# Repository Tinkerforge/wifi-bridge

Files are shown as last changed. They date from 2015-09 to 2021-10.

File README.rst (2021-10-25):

WIFI Bridge
===========

**This product is currently Work In Progress.**

This repository contains the hardware design files.

Repository Content
------------------

hardware/:
 * Contains kicad project files and additionally schematics as pdf

datasheets/:
 * Contains datasheets for sensors and complex ICs that are used

Hardware
--------

The hardware is designed with the open source EDA Suite KiCad
(http://www.kicad.org). Before you are able to open the files,
you have to install the Tinkerforge kicad-libraries
(https://github.com/Tinkerforge/kicad-libraries). You can either clone
them directly in hardware/ or clone them in a separate folder and
symlink them into hardware/
(ln -s kicad_path/kicad-libraries project_path/hardware). After that you
can open the .pro file in hardware/ with kicad and from there view and
modify the schematics and the PCB layout.

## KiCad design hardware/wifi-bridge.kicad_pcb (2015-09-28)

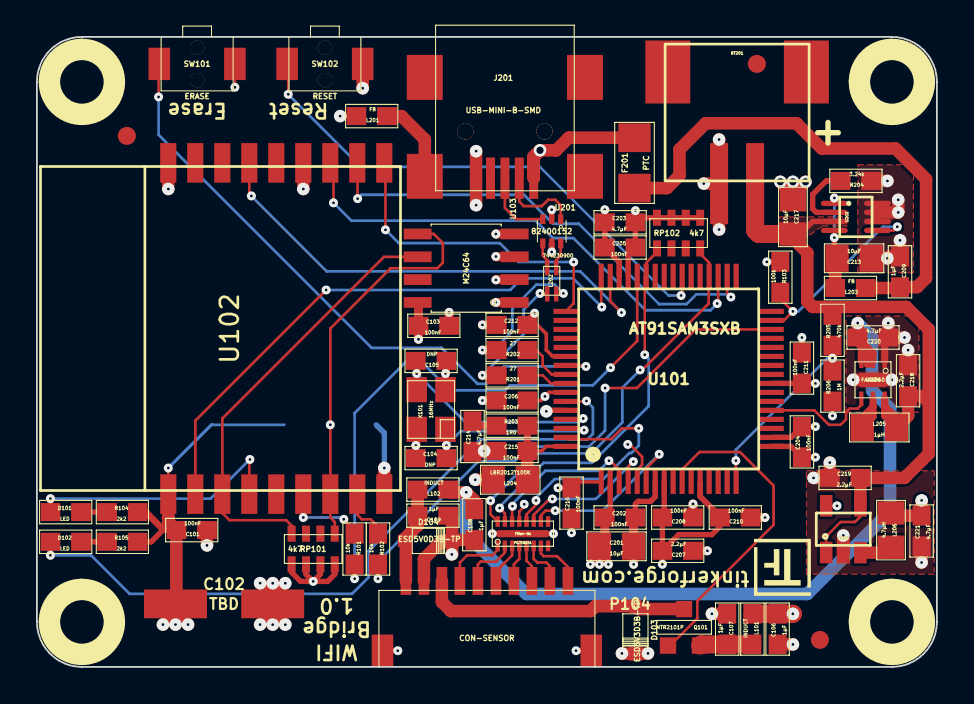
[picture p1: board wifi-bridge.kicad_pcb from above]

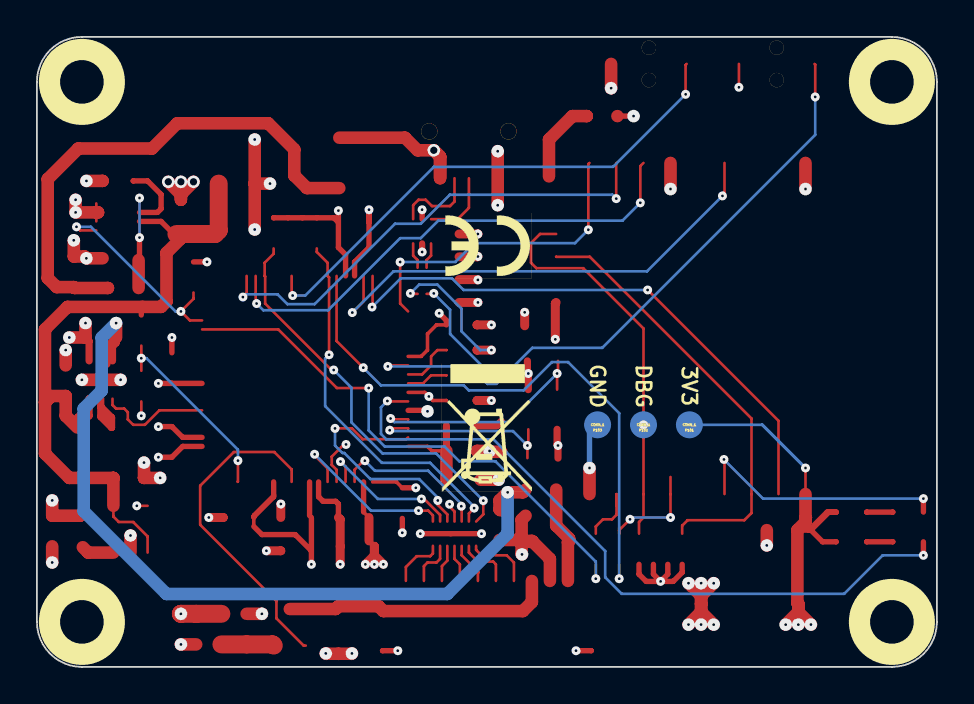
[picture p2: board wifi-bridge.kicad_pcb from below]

Board: 4 copper layers, 50.0 x 35.0 mm, 83 parts (5 on the bottom side), 62 nets.

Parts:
BT201: BATTERY; JST-PH-SM4-2
C101, C103, C202, C204, C205, C206, C208, C210, C211, C212, C215, C216: 100nF; 0603E
C102: TBD; ELKO_63
C104, C105: DNP; 0603E
C106, C107, C108, C109, C209: 1µF; 0603E
C201, C213, C217: 10µF; 0805E
C203, C214, C220, C221: 4.7µF; 0603E
C207, C218, C219: 2.2µF; 0603E
D101, D102: LED; 0603E
D103: ESD3V3D3B-TP; SOD-323
D104: ESD5V0D3B-TP; SOD-323
F201: PTC; 1206E
FILTER101: Filter-8x; DFN16-33x135
Fiducial_Mark: VAL**; Fiducial_Mark
Fiducial_Mark#2, Fiducial_Mark#3: VAL**; Fiducial_Mark
J201: USB-MINI-B-SMD
L101, L102: INDUCT; 0603E
L201, L203: FB; 0603E
L202: 744230900; WE-CNSW-0603
L204: LBR2012T100K; 0805E
L205: 1µH; 0805E
L206: 4.7µH; 0805E
P101, P102, P103: CONN_1; TSTPT
P104: CON-SENSOR
Q101: NTR2101P; SOT23GDS
R101, R102: 10k; 0603E
R103: 100k; 0603E
R104, R105: 2k2; 0603E
R201, R202: 27; 0603E
R203: 1R0; 0603E
R204: 3.24k; 0603E
R205: 470k; 0603E
R206: 1M; 0603E
RP101, RP102: 4k7; 0603X4
SW101: ERASE; TACT-SWITCH
SW102: RESET; TACT-SWITCH
U101: AT91SAM3SXB; LQFP64
U102: ESP8266_WROOM02
U103: M24C64; SOIC8
U104, U105, U106, U107: DRILL; DRILL_NP
U201: 82400152; SOT563-SPEC
U202: AAT3681A; SC70JW-8
U203: PAM2301; TSOT-25
U204: FAN4860; UMLP_22
VAL: WEEE_7mm_back
VAL#2: CE_5mm
X101: 16MHz; CRYSTAL_3225

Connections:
3V3: C101.1, C102.1, C103.2, C106.1, C201.1, C202.1, C203.1, C204.1, C205.1, C206.1, C216.1, C221.1, L101.2, L206.2, P101.1, R103.2, R104.1, R105.1, RP101.1, RP101.2, RP101.3, RP101.4, RP102.1, RP102.2, RP102.3, RP102.4, SW101.2, U101.1, U101.7, U101.18, U101.45, U101.58, U102.1, U103.1, U103.8, U203.5
5VEN: U101.21, U204.4
+5V: C108.1, C220.1, L102.2, U204.2, U204.3
B-ADR: FILTER101.14, U101.3
B-IO1: FILTER101.13, U101.5
B-IO2: FILTER101.12, U101.63
B-IO3: FILTER101.11, U101.4
B-IO4: FILTER101.10, U101.6
B-SCL: FILTER101.16, RP102.8, U101.36
B-SDA: FILTER101.15, RP102.5, U101.43
CHST: R103.1, U101.31, U202.5
D+: R201.2, U101.57
D-: R202.2, U101.56
GND: BT201.2, C101.2, C102.2, C103.1, C104.2, C105.2, C106.2, C107.2, C108.2, C109.2, C201.2, C202.2, C203.2, C204.2, C205.2, C206.2, C207.2, C208.2, C209.2, C210.2, C211.2, C212.2, C213.2, C214.2, C215.2, C216.2, C217.2, C218.2, C219.2, C220.2, C221.2, D103.2, D104.2, FILTER101.EXP, J201.5, L201.1, P103.1, P104.2, P104.EP, R204.2, R206.2, SW102.2, U101.2, U101.17, U101.46, U101.60, U102.9, U102.13, U102.18, U103.2, U103.3, U103.4, U201.2, U202.6, U202.7, U202.8, U203.2, U204.1, U204.EP, X101.3
LED: D102.2, U101.59
unnamed: C104.1, U101.62, X101.1
unnamed: C105.1, U101.61, X101.2
unnamed: C107.1, L101.1, Q101.S
unnamed: C109.1, D104.1, L102.1, P104.1
unnamed: C207.1, C208.1, C210.1, C211.1, C212.1, L204.1, U101.8, U101.12, U101.24, U101.54
unnamed: C209.1, F201.2, L203.2
unnamed: C213.1, L203.1, U202.1, U202.4
unnamed: C214.1, R203.2
unnamed: C215.1, L204.2, R203.1, U101.64
unnamed: D101.1, R104.2
unnamed: D101.2, U102.4
unnamed: D102.1, R105.2
unnamed: D103.1, P104.3, Q101.D
unnamed: F201.1, J201.1, U201.5
unnamed: FILTER101.1, P104.4
unnamed: FILTER101.2, P104.5
unnamed: FILTER101.3, P104.6
unnamed: FILTER101.4, P104.7
unnamed: FILTER101.5, P104.8
unnamed: FILTER101.6, P104.9
unnamed: FILTER101.7, P104.10
unnamed: J201.2, U201.1
unnamed: J201.3, U201.3
unnamed: J201.6, L201.2
unnamed: L202.1, R201.1
unnamed: L202.2, U201.4
unnamed: L202.3, U201.6
unnamed: L202.4, R202.1
unnamed: L205.2, U204.5
unnamed: L206.1, U203.3
unnamed: R101.2, U102.6
unnamed: R102.2, U102.8
unnamed: R204.1, U202.2
unnamed: SW101.1, U101.55
unnamed: SW102.1, U101.39
SW-3V3: Q101.G, U101.10
VBAT: R205.2, R206.1, U101.16
VCC: BT201.1, C217.1, C218.1, C219.1, L205.1, R205.1, U202.3, U203.1, U203.4, U204.6
W-EN: U101.48, U102.2
W-GP: U101.49, U102.10
W-IO0: R102.1, U101.30
W-IO15: R101.1, U101.44
W-RST: U101.47, U102.15
W-RXD: U101.34, U102.11
W-SCL: RP101.8, U102.3, U103.6
W-SDA: P102.1, RP101.5, U102.7, U103.5
W-TXD: U101.35, U102.12

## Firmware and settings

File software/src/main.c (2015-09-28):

/* stepper-brick
 * Copyright (C) 2010-2013 Olaf Lüke <olaf@tinkerforge.com>
 *
 * main.c: Stepper Brick startup code
 *
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
 * You should have received a copy of the GNU Lesser General Public
 * License along with this library; if not, write to the
 * Free Software Foundation, Inc., 59 Temple Place - Suite 330,
 * Boston, MA 02111-1307, USA.
 */

#include <stdbool.h>
#include <stdint.h>
#include <stdio.h>
#include <stdlib.h>

#include "bricklib/free_rtos/include/FreeRTOS.h"
#include "bricklib/free_rtos/include/task.h"

#include "bricklib/com/i2c/i2c_pca9549/i2c_pca9549.h"
#include "bricklib/com/spi/spi_stack/spi_stack_master.h"
#include "bricklib/com/spi/spi_stack/spi_stack_slave.h"
#include "bricklib/com/spi/spi_stack/spi_stack_common.h"
#include "bricklib/com/i2c/i2c_eeprom/i2c_eeprom_master.h"
#include "bricklib/com/i2c/i2c_eeprom/i2c_eeprom_slave.h"
#include "bricklib/com/usb/usb.h"
#include "bricklib/logging/logging.h"
#include "bricklib/bricklet/bricklet_init.h"
#include "bricklib/drivers/uid/uid.h"
#include "bricklib/drivers/wdt/wdt.h"
#include "bricklib/drivers/pio/pio.h"
#include "bricklib/utility/init.h"
#include "bricklib/utility/profiling.h"
#include "bricklib/utility/led.h"
#include "bricklib/logging/logging.h"

#include "config.h"
#include "bricklib/utility/util_definitions.h"

void vApplicationStackOverflowHook(xTaskHandle *pxTask, signed char *pcTaskName) {
	while(true);
}

int main() {

	brick_init();
	led_init();
	Pin ch_st = PIN_CH_ST;
	PIO_Configure(&ch_st, 1);
	while(1) {	
		if(PIO_Get(&ch_st)) {
			led_toggle(LED_STD_BLUE);
		}
		else {
			led_on(LED_STD_BLUE);
		}
		SLEEP_MS(100);
		wdt_restart();
	}
}

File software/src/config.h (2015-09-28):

/* wifi-bridge
 * Copyright (C) 2015 Bastian Nordmeyer <bastian@tinkerforge.com>
 *
 * config.h: Wifi-Bridge specific configuration
 *
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
 * You should have received a copy of the GNU Lesser General Public
 * License along with this library; if not, write to the
 * Free Software Foundation, Inc., 59 Temple Place - Suite 330,
 * Boston, MA 02111-1307, USA.
 */

#ifndef CONFIG_H
#define CONFIG_H

#include "bricklib/drivers/board/sam3s/SAM3S.h"
#include <stdbool.h>

#define BRICK_FIRMWARE_VERSION_MAJOR 1
#define BRICK_FIRMWARE_VERSION_MINOR 0
#define BRICK_FIRMWARE_VERSION_REVISION 0

#define BRICK_HARDWARE_VERSION_MAJOR 1
#define BRICK_HARDWARE_VERSION_MINOR 0
#define BRICK_HARDWARE_VERSION_REVISION 0

#define BRICK_DEVICE_IDENTIFIER 15

// ************** DEBUG SETTINGS **************
#define DEBUG_SPI_STACK 1
#define DEBUG_I2C_EEPROM 0
#define DEBUG_STARTUP 1
#define DEBUG_BRICKLET 1
#define DEBUG_STEPPER 1
//#define PROFILING
//#define PROFILING_TIME 100 // After how many seconds profiling is printed

#define DISABLE_JTAG_ON_STARTUP
//#define LOGGING_SERIAL
//#define LOGGING_LEVEL LOGGING_DEBUG
#define LOGGING_LEVEL LOGGING_NONE


// ************** BRICK SETTINGS **************

// Frequencies
#define BOARD_MCK      64000000 // Frequency of brick
#define BOARD_MAINOSC  16000000 // Frequency of oscillator
#define BOARD_ADC_FREQ 16000000 // Frequency of ADC
#define BOARD_OSC_EXTERNAL      // Use external oscillator


// UART for console output (printf)
#define PIN_CONSOLE_RXD  {1 << 21, PIOA, ID_PIOA, PIO_PERIPH_A, PIO_DEFAULT}
#define PIN_CONSOLE_TXD  {1 << 22, PIOA, ID_PIOA, PIO_PERIPH_A, PIO_DEFAULT}

#define CONSOLE_BAUDRATE 115200
#define CONSOLE_USART    USART1
#define CONSOLE_ID       ID_USART1
#define CONSOLE_PINS     {PIN_CONSOLE_RXD, PIN_CONSOLE_TXD}

#define PINS_UART        {PIN_CONSOLE_RXD, PIN_CONSOLE_TXD}

// TWI
// TWI version
#define TWI_V3XX

// TWI stack definitions (for reading of eeproms from Bricks in stack)
#define TWI_STACK           TWI1
#define PIN_TWI_TWD_STACK   {1 << 4, PIOB, ID_PIOB, PIO_PERIPH_A, PIO_DEFAULT}
#define PIN_TWI_TWCK_STACK  {1 << 5, PIOB, ID_PIOB, PIO_PERIPH_A, PIO_DEFAULT}
#define PINS_TWI_STACK      PIN_TWI_TWD_STACK, PIN_TWI_TWCK_STACK

// TWI bricklet definitions (for bricklets, spi select and brick specific
//                           functions)
#define TWI_BRICKLET           TWI0
#define PIN_TWI_TWD_BRICKLET   {1 << 3, PIOA, ID_PIOA, PIO_PERIPH_A, PIO_DEFAULT}
#define PIN_TWI_TWCK_BRICKLET  {1 << 4, PIOA, ID_PIOA, PIO_PERIPH_A, PIO_DEFAULT}
#define PINS_TWI_BRICKLET      PIN_TWI_TWD_BRICKLET, PIN_TWI_TWCK_BRICKLET

// USB
// USB VBUS monitoring pin for USB plug and play
#define PIN_USB_DETECT  {1 << 26, PIOA, ID_PIOA, PIO_INPUT, PIO_DEFAULT}
// USB product descriptor (name of brick)
#define PRODUCT_DESCRIPTOR { \
	USBStringDescriptor_LENGTH(13), \
    USBGenericDescriptor_STRING, \
    USBStringDescriptor_UNICODE('S'), \
    USBStringDescriptor_UNICODE('t'), \
    USBStringDescriptor_UNICODE('e'), \
    USBStringDescriptor_UNICODE('p'), \
    USBStringDescriptor_UNICODE('p'), \
    USBStringDescriptor_UNICODE('e'), \
    USBStringDescriptor_UNICODE('r'), \
    USBStringDescriptor_UNICODE(' '), \
    USBStringDescriptor_UNICODE('B'), \
    USBStringDescriptor_UNICODE('r'), \
    USBStringDescriptor_UNICODE('i'), \
    USBStringDescriptor_UNICODE('c'), \
    USBStringDescriptor_UNICODE('k') \
}


// SPI
#define PIN_SPI_MISO        {1 << 12, PIOA, ID_PIOA, PIO_PERIPH_A, PIO_DEFAULT}
#define PIN_SPI_MOSI        {1 << 13, PIOA, ID_PIOA, PIO_PERIPH_A, PIO_DEFAULT}
#define PIN_SPI_SPCK        {1 << 14, PIOA, ID_PIOA, PIO_PERIPH_A, PIO_DEFAULT}

#define PINS_SPI            PIN_SPI_MISO, PIN_SPI_MOSI, PIN_SPI_SPCK

#define PIN_SPI_SELECT_SLAVE  {1 << 11, PIOA, ID_PIOA, PIO_PERIPH_A, PIO_DEFAULT}

// LED
#define PIN_LED_STD_BLUE    {1 <<13, PIOB, ID_PIOB, PIO_OUTPUT_1, PIO_DEFAULT}
//#define PIN_LED_STD_RED     {1 << 10, PIOA, ID_PIOA, PIO_OUTPUT_1, PIO_DEFAULT}
#define PINS_STD_LED        PIN_LED_STD_BLUE
#define PINS_LED            PINS_STD_LED

#define LED_STD_BLUE        0
#define LED_STD_RED         1


// Brick Detect
// Set low by master
// TODO: Change name
#define PIN_DETECT        {1 << 6, PIOB, ID_PIOB, PIO_OUTPUT_0, PIO_DEFAULT}

// Pin charge status
#define PIN_CH_ST        {1 << 8, PIOA, ID_PIOA, PIO_INPUT, PIO_PULLUP}



// ************** INTERRUPT PRIORITIES ***********
#define PRIORITY_EEPROM_MASTER_TWI0  1
#define PRIORITY_EEPROM_SLAVE_TWI1   1
#define PRIORITY_STACK_SLAVE_SPI     5
#define PRIORITY_PROFILING_TC0       0
#define PRIORITY_STEPPER_TC0         6

// ************** BRICKLET SETTINGS **************

// Number of bricklet ports
#define BRICKLET_NUM 2

// BRICKLET A
#define BRICKLET_A_ADDRESS 84
#define BRICKLET_A_ADC_CHANNEL 4
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

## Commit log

2015-09-09 first schematic parts added, many connections missing, prepare first placement
    [power.sch, processor.sch, wifi-bridge.kicad_pcb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]
2015-09-09 new placement idea
    [power.sch, wifi-bridge.kicad_pcb, wifi-bridge.sch]
2015-09-09 missing commit, things changed
    [wifi-bridge.sch]
2015-09-10 new placement mockup
    [wifi-bridge.kicad_pcb]
2015-09-11 placement complete
    [wifi-bridge.kicad_pcb, wifi-bridge.sch]
2015-09-11 fixed schematic, add tvs diodes, placement changed, clear for routing
    [power.sch, wifi-bridge.kicad_pcb, wifi-bridge.sch]
2015-09-11 fully routed
    [wifi-bridge.kicad_pcb]
2015-09-11 add planes, add logos etc.
    [wifi-bridge.kicad_pcb]
2015-09-11 round corners
    [wifi-bridge.kicad_pcb]
2015-09-11 version for prototype order
    [wifi-bridge.kicad_pcb]
2015-09-22 add hints to the schematic, add demo code
    [power.sch, wifi-bridge.kicad_pcb, wifi-bridge.sch]
2015-09-28 bugfix erase button was connected to GND
    [wifi-bridge.sch]
2015-09-28 fix pcb (erase button to vcc)
    [wifi-bridge.kicad_pcb]
2015-09-28 fix powering problem when battery is not connected
    [power.sch, wifi-bridge.sch]
2015-09-28 add lipo connector hint
    [power.sch]
2015-09-28 charging detect implemented
2021-10-25 Update KiCad link
    https://www.kicad.org/blog/2021/10/Avoid-links-to-former-kicad-domain/

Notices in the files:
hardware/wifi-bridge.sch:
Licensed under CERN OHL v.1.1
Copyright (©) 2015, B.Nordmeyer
